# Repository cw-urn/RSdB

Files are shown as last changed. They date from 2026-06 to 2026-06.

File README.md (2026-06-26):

# RSdB
> What is this?
- RSdB (rim shot dB) is a general usage dB meter with an OLED display, powered by the MEMS MSM261DGT003 and a Seeed XIAO RP2040.
> How do you use it?
- Plug straight into a generic USB-C power bank, and start measuring right away!
> Why did I make this?
- Primarily to not annoy my neighbours. It's nice knowing how loud I'm playing at any given moment so I know I need to chill down on the heavy hits. Secondarily, I didn't have any major experience with PDM microphones before, so I thought this would be a great place to start.

# Firmware
Firmware can be found at main/firmware.

The microphone I chose doesn't send traditional audio signals, instead it sends a single stream of ones and zeros at roughly 2 MHz. So one bit per clock pulse. The important part here is that stream having a bunch of repeating numbers after another.

If it sends a bunch of ones, then the sound pressure is high, and sends a bunch of zeros when it's low. The XIAO generates the clock, and reads the DATA pin at the same time. Once enough bits have accumulated, a decimation filter takes over, and it applies a low-pass sinc filter across every 128 bits and collapses them into a single 16-bit PCM sample, throwing away the ultrasonic noise the oversampling introduced and leaving just the audio band. This produces 16,000 audio samples per second.

From there, the firmware squares and accumulates every sample over a one-second window, computes the RMS amplitude (a measure of average signal energy that correctly handles the fact that audio oscillates both positive and negative), converts the result to dBFS using a base-10 logarithm, and then applies a sensitivity offset derived from the microphone's datasheet to produce an approximate reading in dB SPL. This calculation part was really tricky and I just couldn't figure out the math myself. Used AI for that part.

# PCB

<hr>

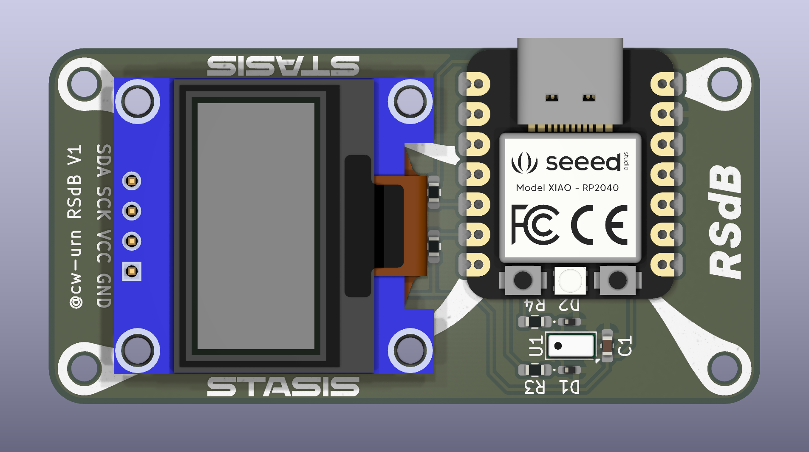
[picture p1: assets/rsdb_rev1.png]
3D render


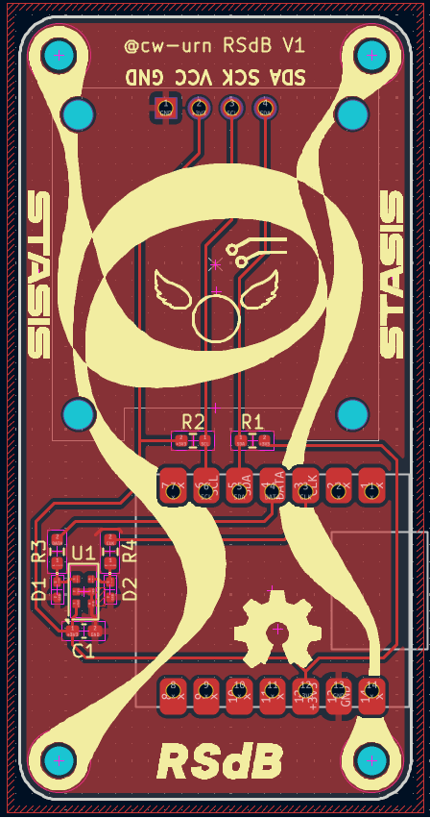
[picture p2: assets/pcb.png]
PCB


<hr>

## BOM

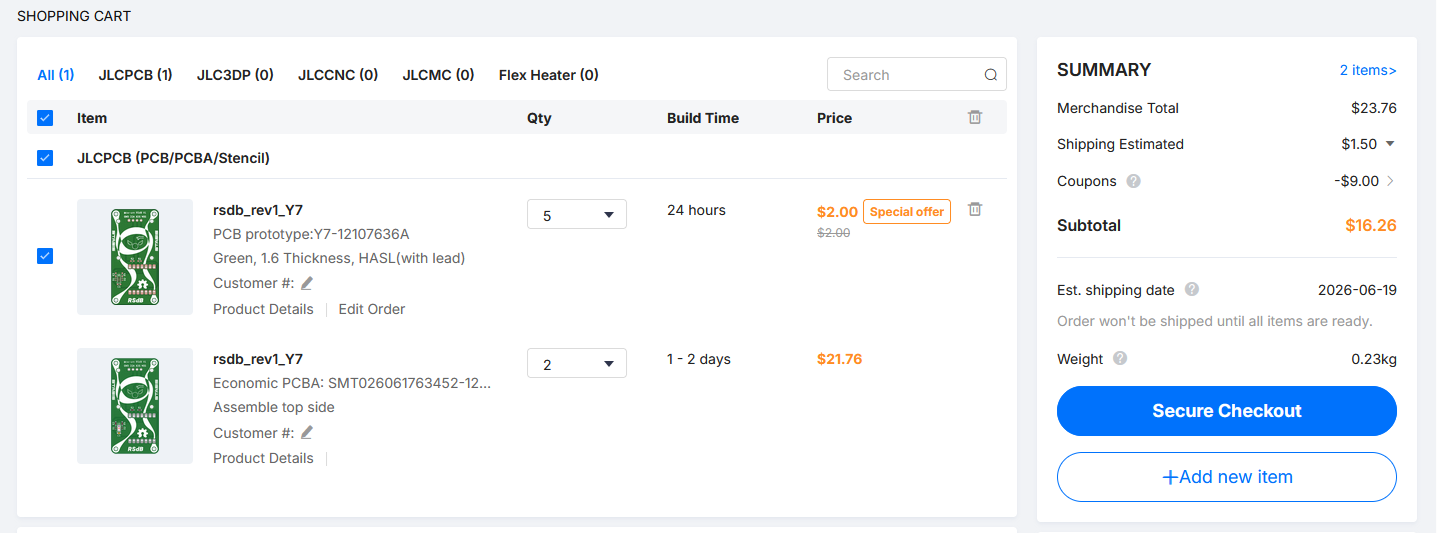
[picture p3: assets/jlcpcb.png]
JLCPCB cart


| Item | Quantity | Price | Funding required | Link |
| :---: | :---: | :---: | :---: | :---: |
| PCB | 1 | 16.26\* | Yes | [JLCPCB](https://jlcpcb.com/) |
| SSD1306 128×64 Mono 0.96 Inch I2C OLED Display | 1 | - | No | None |
| Seeed Studio XIAO RP2040 | 1 | - | No | None |

\* Note that price might fluctuate based on LCSC component prices, and the availability of coupons at the time of purchase. Includes PCBA.

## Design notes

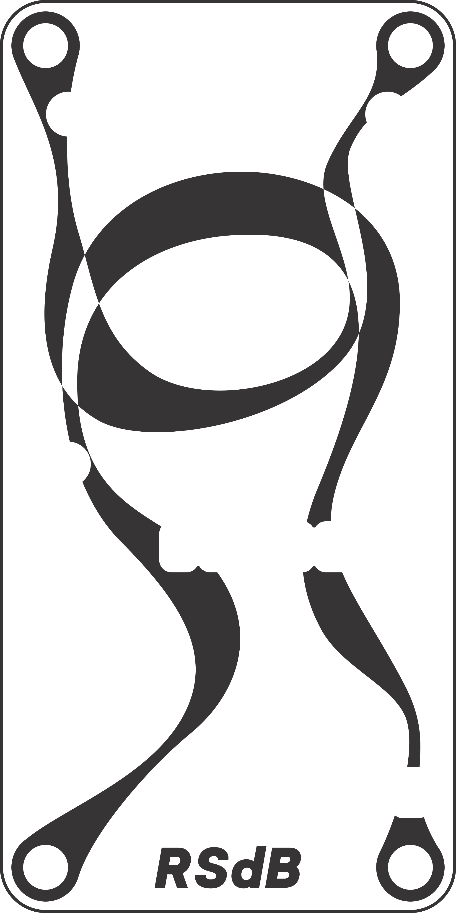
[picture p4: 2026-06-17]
pcb/silkscreen/front.png

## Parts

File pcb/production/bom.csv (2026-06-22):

Designator | Footprint | Quantity | Value | LCSC Part #
C1 | 0603 | 1 | 0.1uF
D1, D2 | 0402 | 2 | PESD5V0F1BL
J1 | OLED_128x64 | 1 | OLED_128x64
R1, R2 | 0603 | 2 | 4.7k
R3, R4 | 0603 | 2 | 30
U1 | MSM261DGT003 | 1 | MSM261DGT003
U2 | Seeed_XIAO_RP2040 | 1 | MCU_Seeed_XIAO_RP2040

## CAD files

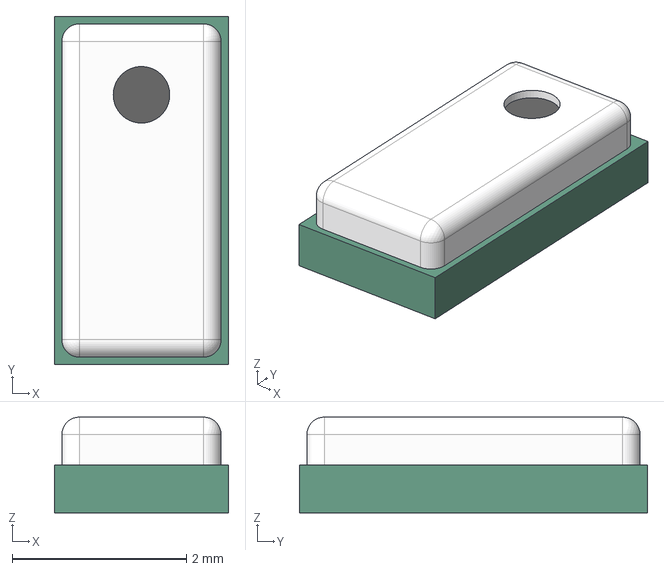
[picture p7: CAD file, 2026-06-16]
pcb/3d models/MSM261DGT003.step
2.00 x 4.00 x 1.10 mm

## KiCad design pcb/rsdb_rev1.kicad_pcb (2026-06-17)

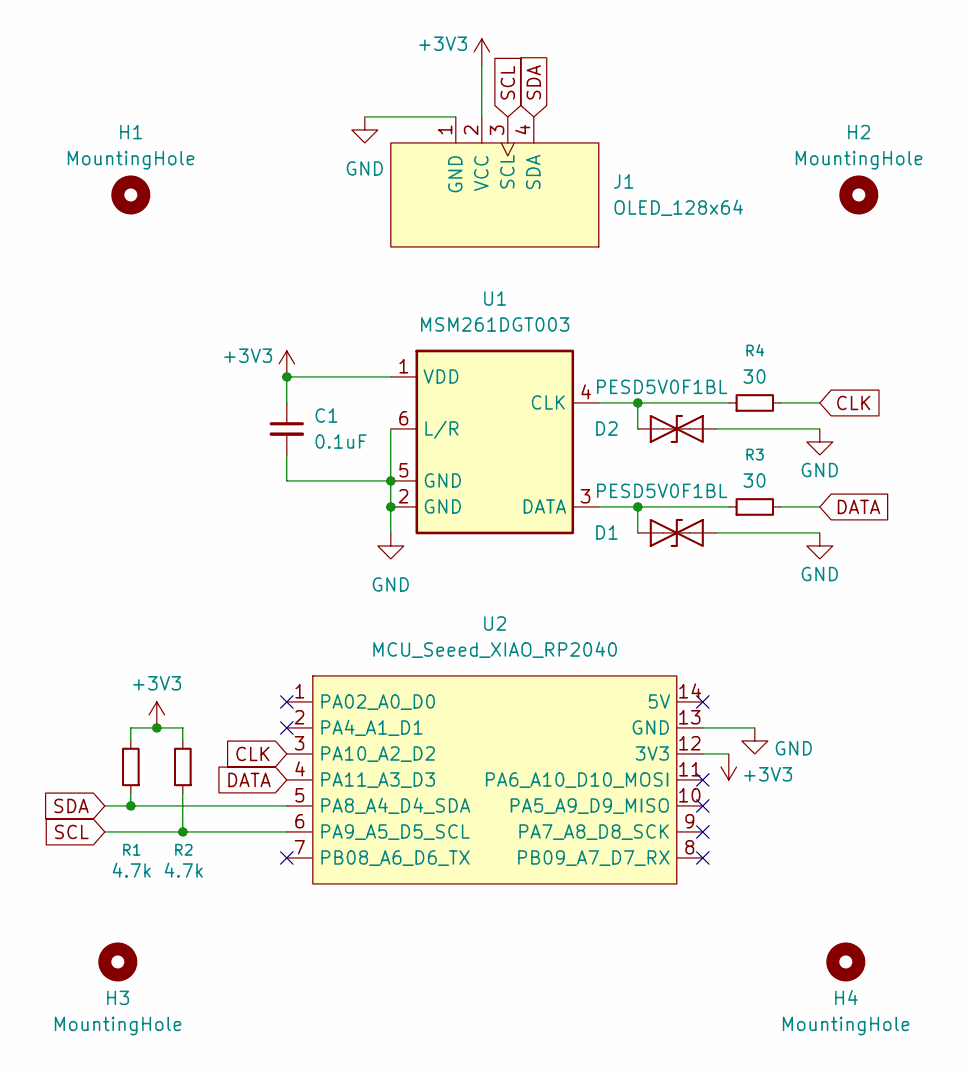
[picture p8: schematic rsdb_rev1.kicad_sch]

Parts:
C1: 0.1uF; C_0603_1608Metric_Pad1.08x0.95mm_HandSolder
D1, D2: PESD5V0F1BL; D_0402_1005Metric_Pad0.77x0.64mm_HandSolder
H1, H2, H3, H4: MountingHole; MountingHole_2.2mm_M2
J1: OLED_128x64
R1, R2: 4.7k; R_0603_1608Metric_Pad0.98x0.95mm_HandSolder
R3, R4: 30; R_0603_1608Metric_Pad0.98x0.95mm_HandSolder
U1: MSM261DGT003
U2: MCU_Seeed_XIAO_RP2040; Seeed_XIAO_RP2040

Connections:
+3V3: C1.1, J1.2 (VCC), R1.2, R2.2, U1.1 (VDD), U2.12 (3V3)
CLK: R4.2, U2.3 (PA10_A2_D2)
DATA: R3.2, U2.4 (PA11_A3_D3)
GND: C1.2, D1.2 (A2), D2.2 (A2), J1.1 (GND), U1.2 (GND), U1.5 (GND), U1.6 (L/R), U2.13 (GND)
unnamed: D1.1 (A1), R3.1, U1.3 (DATA)
unnamed: D2.1 (A1), R4.1, U1.4 (CLK)
SCL: J1.3 (SCL), R2.1, U2.6 (PA9_A5_D5_SCL)
SDA: J1.4 (SDA), R1.1, U2.5 (PA8_A4_D4_SDA)

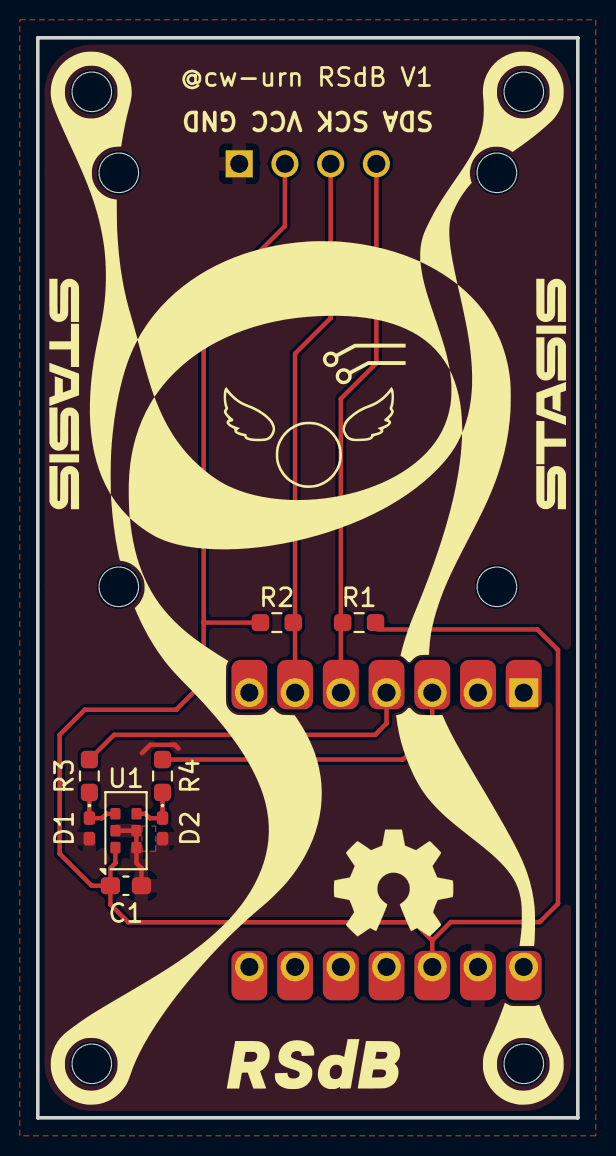
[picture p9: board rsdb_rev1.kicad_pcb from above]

Board: 2 copper layers, 30.0 x 60.0 mm, 14 parts (0 on the bottom side), 8 nets.

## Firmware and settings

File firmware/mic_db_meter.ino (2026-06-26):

#include <PDM.h> // microphone library
#include <Wire.h> // I2C library
#include <Adafruit_GFX.h> // graphics
#include <Adafruit_SSD1306.h> // library for the oled
#include <math.h>

#define MIC_CLK_PIN   D2 // pins
#define MIC_DATA_PIN  D3

#define SCREEN_WIDTH  128 // basic setup stuff
#define SCREEN_HEIGHT 64
#define OLED_RESET    -1
#define OLED_I2C_ADDR 0x3C // not too sure about this i might have to change it
Adafruit_SSD1306 display(SCREEN_WIDTH, SCREEN_HEIGHT, &Wire, OLED_RESET);

static const int CHANNELS = 1; // mono
static const int SAMPLE_RATE = 16000; // mic's sample rate is 16kHz
short sampleBuffer[512]; // buffer to hold PDM samples // short is basically an integer
                         // 512 samples at 16kHz is 32ms of audio

volatile double sumSquares = 0; // holds the running sum of every sample squared
volatile uint32_t sampleCount = 0; // tracks how many samples have gone into that sum
                                   // volatile because theyr written from an interrupt service routine and read from the main loop

static const float SPL_OFFSET_DB = 120.0; // this is a guess. the datasheet says it typically ranges from -26 dBFS at 94 dB SPL so 94--26 = 120.

uint32_t lastUpdate = 0; // uint32_t is millis()'s return type

void onPDMdata() { // function to handle incoming PDM data
  int bytesAvailable = PDM.available();
  PDM.read(sampleBuffer, bytesAvailable); // reads
  int samplesRead = bytesAvailable / 2; // 2 bytes per sample
  for (int i = 0; i < samplesRead; i++) { 
    sumSquares += (double)sampleBuffer[i] * (double)sampleBuffer[i];
  }
  sampleCount += samplesRead; // for rms calculation
}

void setup() {
  Serial.begin(115200); // usb port for debugging

  Wire.begin(); // start the I2C bus on the default pins
  if (!display.begin(SSD1306_SWITCHCAPVCC, OLED_I2C_ADDR)) {
    Serial.println("SSD1306 not found");
    while (1) { delay(10); }
  }
  display.clearDisplay(); // make it black
  display.setTextColor(SSD1306_WHITE); // make the text white
  display.setTextSize(1); // set the text size to 1
  display.setCursor(0, 0); // set the cursor to the top left
  display.println("Starting mic..."); // print to the display
  display.display(); // display the display lmao

  PDM.setCLK(MIC_CLK_PIN); // clock
  PDM.setDIN(MIC_DATA_PIN); // data
  PDM.onReceive(onPDMdata); // set the function to be called when data is available

  if (!PDM.begin(CHANNELS, SAMPLE_RATE)) {
    display.clearDisplay();
    display.setCursor(0, 0);
    display.println("PDM init failed!");
    display.display();
    while (1) { delay(10); }
  }

  lastUpdate = millis(); // one second timer for the loop to update the display every second
}

void loop() {
  if (millis() - lastUpdate >= 1000) {
    lastUpdate += 1000;

    noInterrupts(); // disable interrupts for a couple milliseconds
    double ss = sumSquares;
    uint32_t n = sampleCount;
    sumSquares = 0;
    sampleCount = 0;
    interrupts();

    float dbSPL = 0;
    if (n > 0) {
      double rms = sqrt(ss / (double)n); // rms formula: sqrt(sum of squares / number of samples)
      if (rms < 1.0) {
        rms = 1.0; // log10(0) is undefined, so rms to 1.0 to avoid that
      }
      float dbFS = 20.0 * log10(rms / 32768.0); 
      dbSPL = dbFS + SPL_OFFSET_DB; // final dB calculatiuon!!!! convert from dBFS to dB SPL
    }

    Serial.print("dB SPL (approx): ");
    Serial.println(dbSPL, 1); // print it

    display.clearDisplay(); // clear it
    display.setTextSize(2); // make it bigger
    display.setCursor(0, 16); // set the cursor to the middle of the screen
    display.print(dbSPL, 1); // print the dB SPL to the display
    display.println(" dB"); // print the unit
    display.display(); // display the display again
  }
}
